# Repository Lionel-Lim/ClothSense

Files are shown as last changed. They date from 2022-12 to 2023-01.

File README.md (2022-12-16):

# ClothSense

CASA0016

DY Lim

* * *

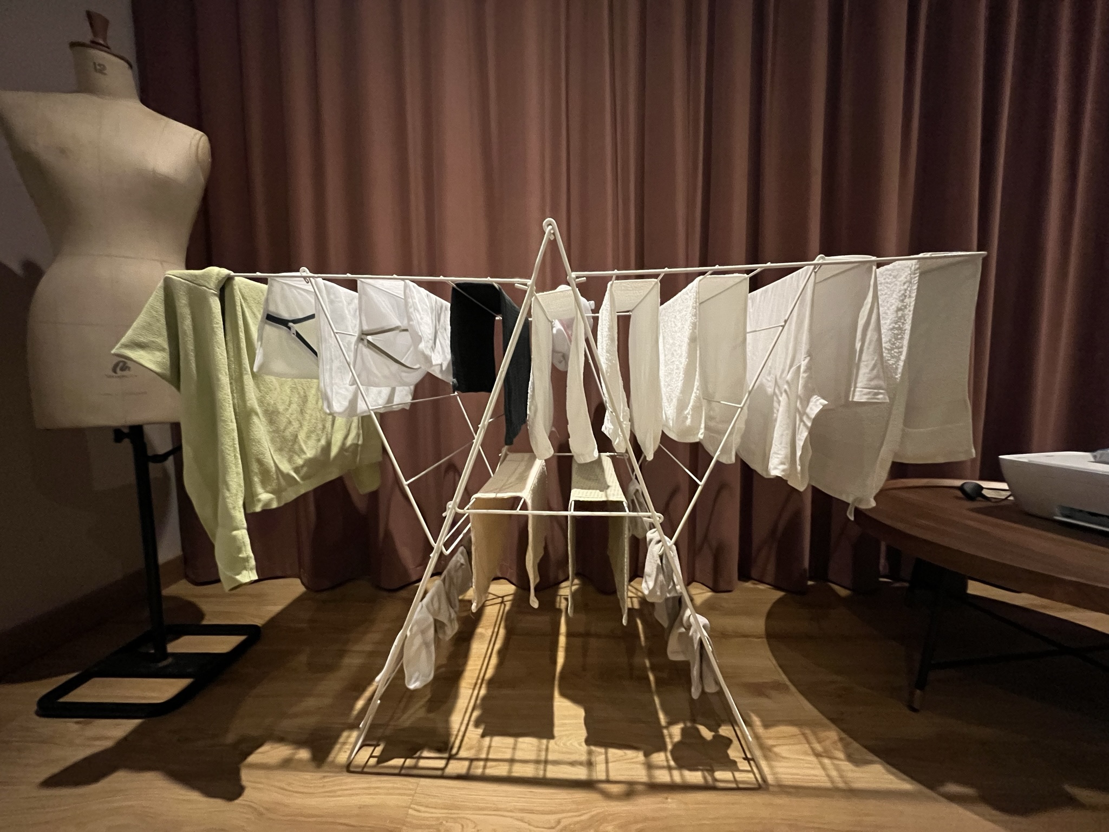
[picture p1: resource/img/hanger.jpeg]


## When is it going to be dried?

###   

### No dryer.

Energy Bill, Damage on cloth, Noise...

Every time I needed to touch the cloth to check whether it is dried or still wet.

However, it is **_hard to predict_** even if i do so. 

Also, I want to **_boost the drying process_** and want to **_know the condition_** where it is located(Bad air quality, weather).

ClothSense is going to  **monitor**:

- Temperature
- Humidity
- ~~Air Quality~~

ClothSense is going to **boost**:

- Dry State

ClothSense is going to **show:**

- Estimated Time to dry
- Current Environmental Condition

###   

## Component

- Arduino Uno (MCU)
- ~~BME680~~ DHT22 (Environment Sensor) - Digital Pin
- max7219 LED Matrix 8x32 (Display) - SPI
- NF-F12 5V PMW (Fan) - PWM
- Buttons - Digital Pin

## Workflow

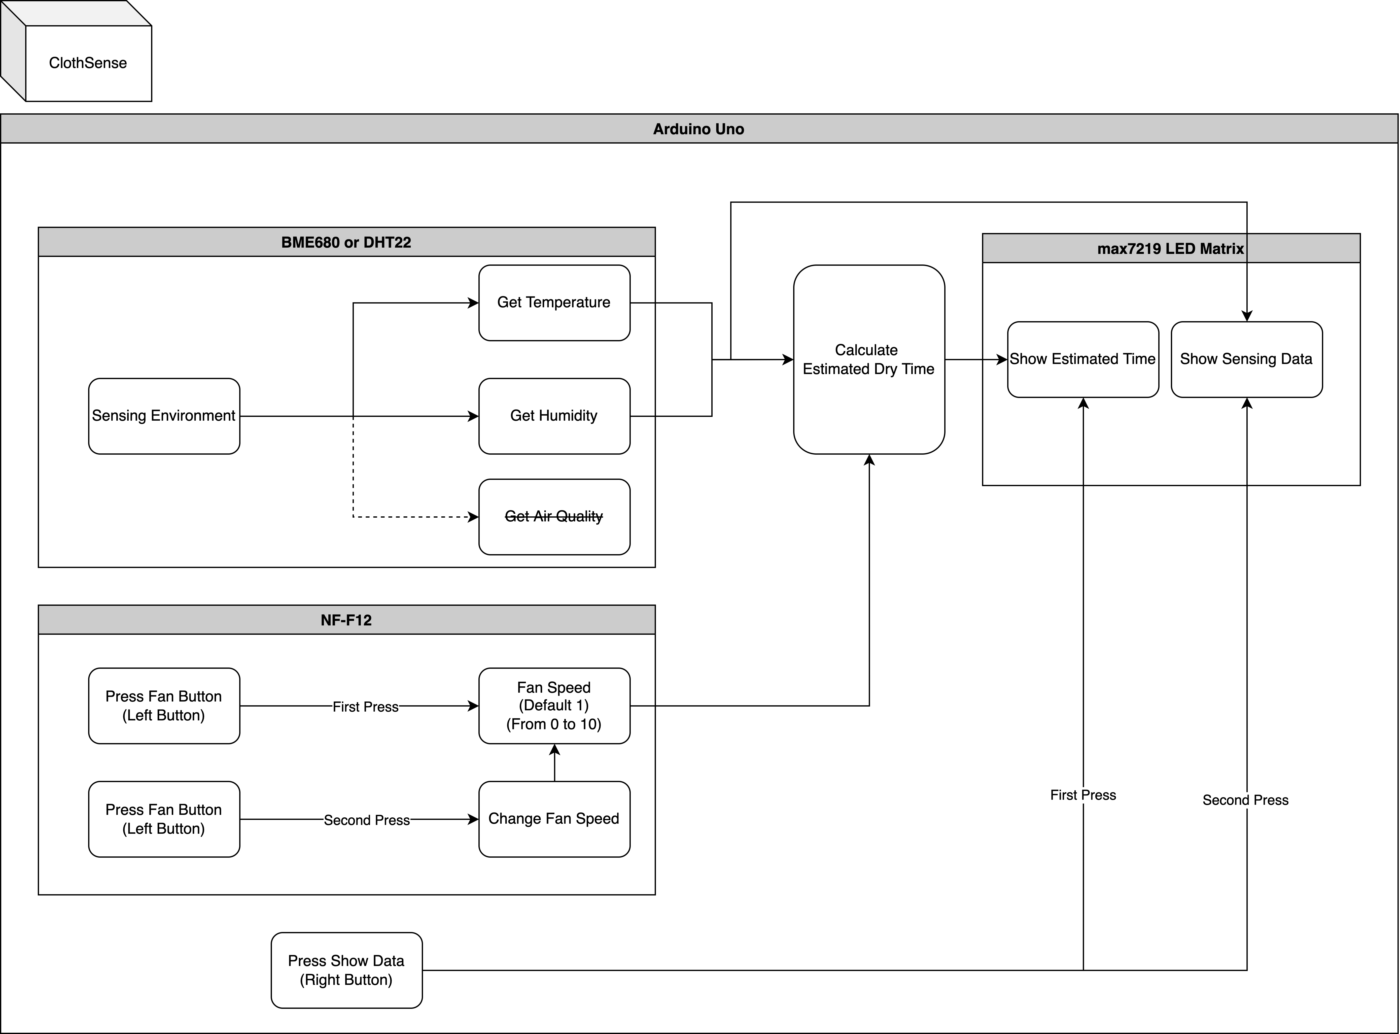
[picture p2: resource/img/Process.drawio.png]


## Build Process

### First Prototype

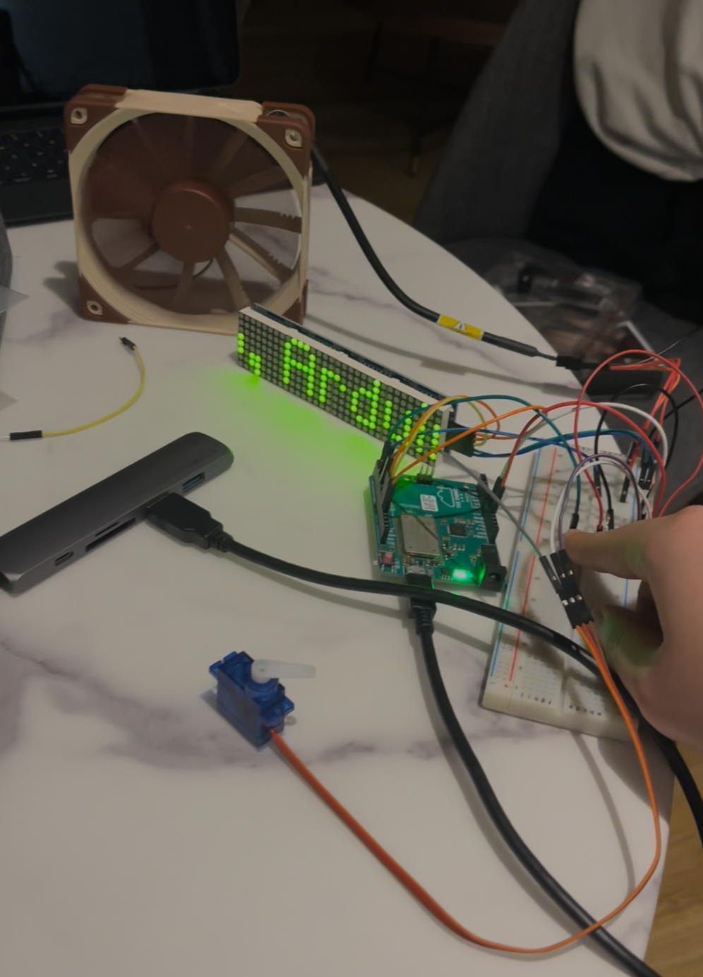
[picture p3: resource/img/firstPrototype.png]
  

Tested Fan Control using PWM control

By pressing button, Uno changes fan speed for noise control.

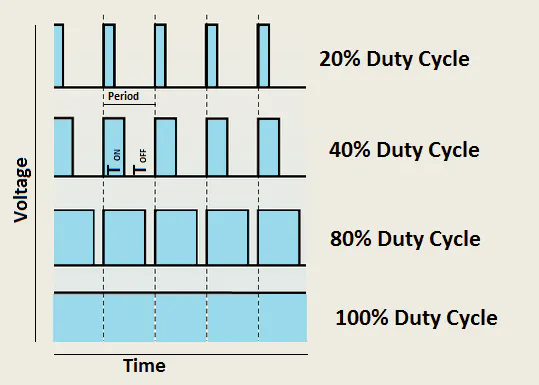
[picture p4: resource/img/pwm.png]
  

[Arduino PWM Tutorial - Arduino Project Hub](https://create.arduino.cc/projecthub/muhammad-aqib/arduino-pwm-tutorial-ae9d71)  

### Second Prototype

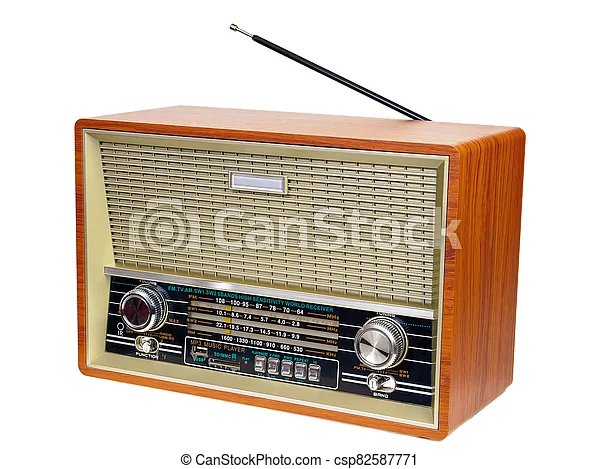
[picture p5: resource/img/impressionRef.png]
  

[Old-fashioned vintage radio isolated on a white background - | CanStock (canstockphoto.com)](https://www.canstockphoto.com/old-fashioned-vintage-radio-isolated-on-82587771.html)  

Inspired by the old fashion radios, got the idea from Prof. Andy.

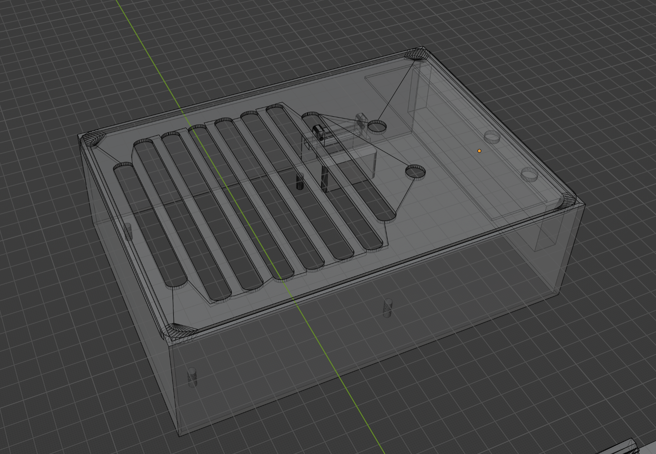
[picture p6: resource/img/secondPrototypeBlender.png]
  

3D Printing Enclosure

- Slow
- Not Precise
- Good for 3d solid object prototyping

Removed servo

Moved LED Matrix

Changed sie

### Third Prototype

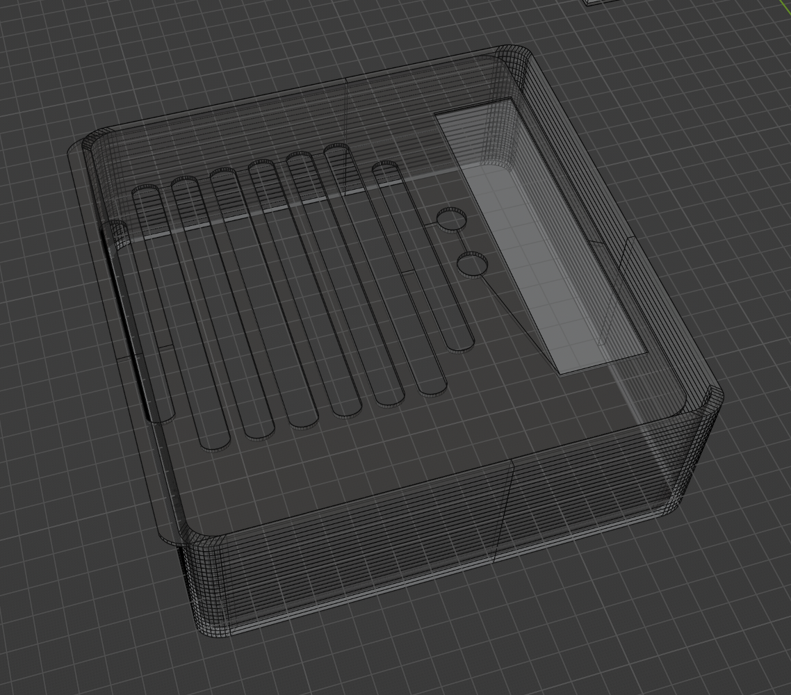
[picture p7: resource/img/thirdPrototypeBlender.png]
  

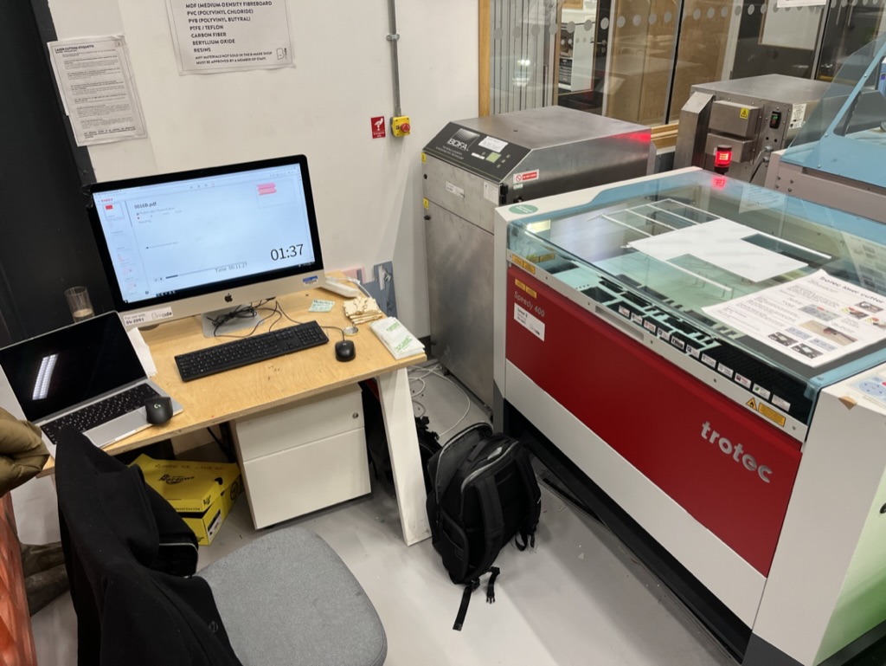
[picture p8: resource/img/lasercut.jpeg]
  

Laser cut wood enclosure

- Fast
- Precise

3D Printed top lid to hide LED matrix and for aesthetic reason

with the enclosure, the device was tested and some problems are found:

1. BME680 library uses more than 30% of maximum sketch storage. (From 70% to 117%)

- [Reduce the size and memory usage of your sketch – Arduino Help Center](https://support.arduino.cc/hc/en-us/articles/360013825179-Reduce-the-size-and-memory-usage-of-your-sketch)  
    
- Remove BME680 and use  DHT22
- Use Arduino Uno instead of Leonardo (LoRa Library)
- Optimised variables and functions

3. Did not design the component mounting

- Made some mounting brackets
- ![](./resource/img/lasercutBracket.jpeg  

### Final Build

Modularised parts

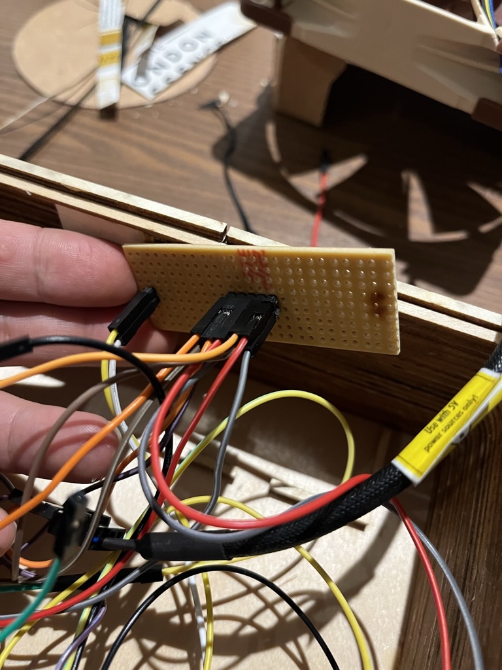
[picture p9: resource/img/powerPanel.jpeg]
 

Used DHT22

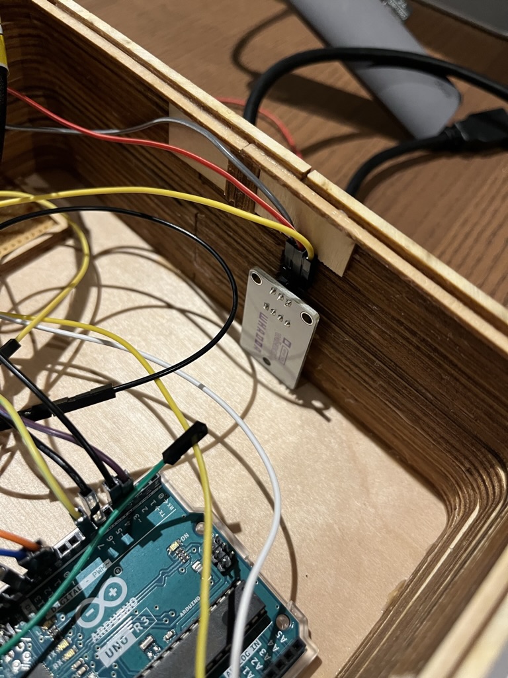
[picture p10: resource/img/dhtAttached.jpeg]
  

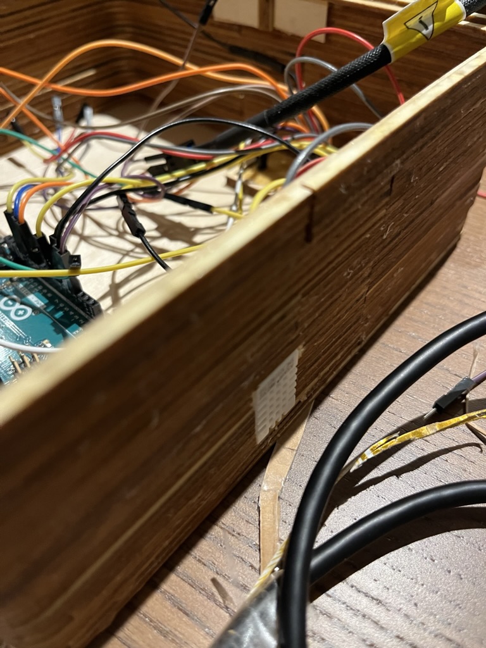
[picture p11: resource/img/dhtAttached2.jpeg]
  

Added mesh to prevent the interference between the fan and wires

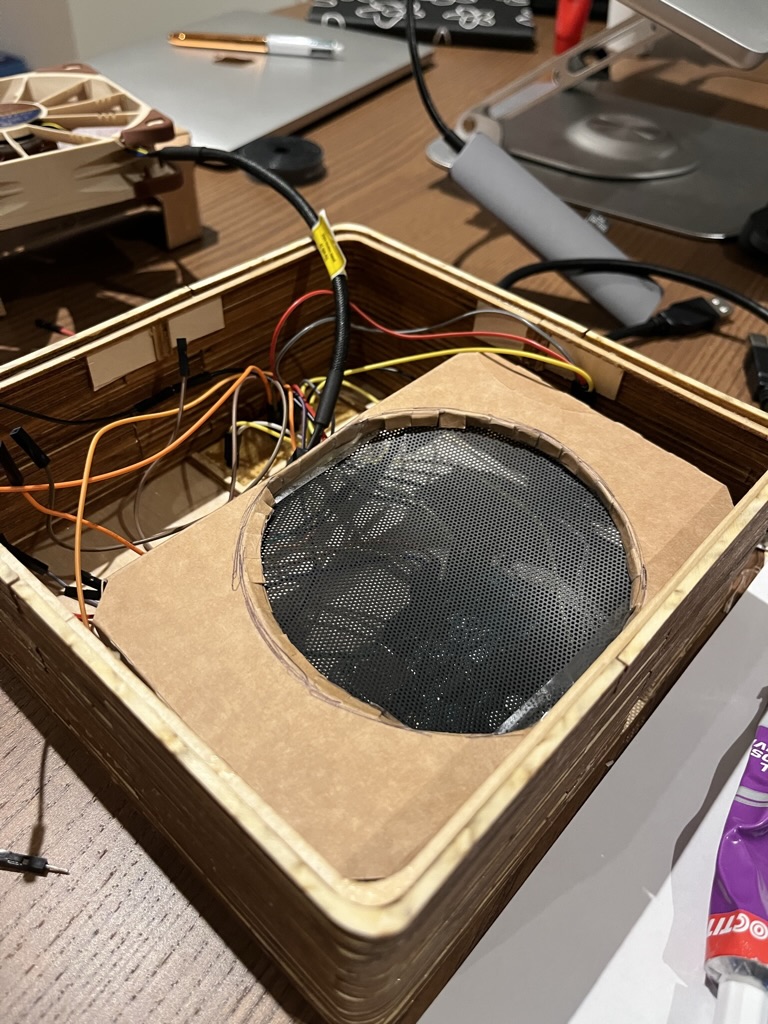
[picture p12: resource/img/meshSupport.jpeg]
  

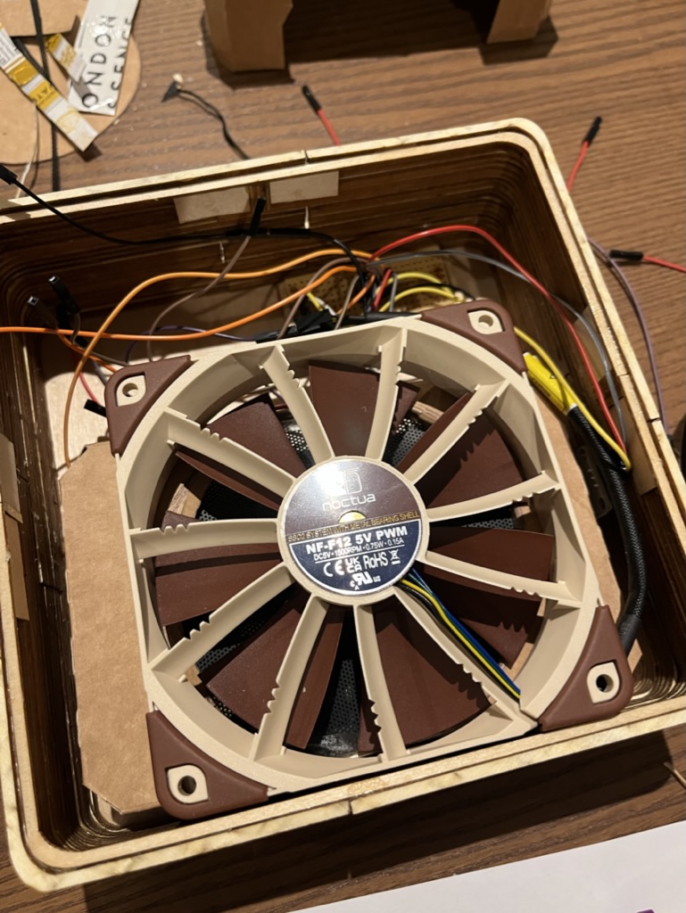
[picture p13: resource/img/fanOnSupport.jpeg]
  

Introduced the mounting bracket

  

Result

[demo](https://drive.google.com/file/d/1XH3c2ZzTV_dLAC6Vp6ikhxQ3ZIhcOEiU/view?usp=share_link)

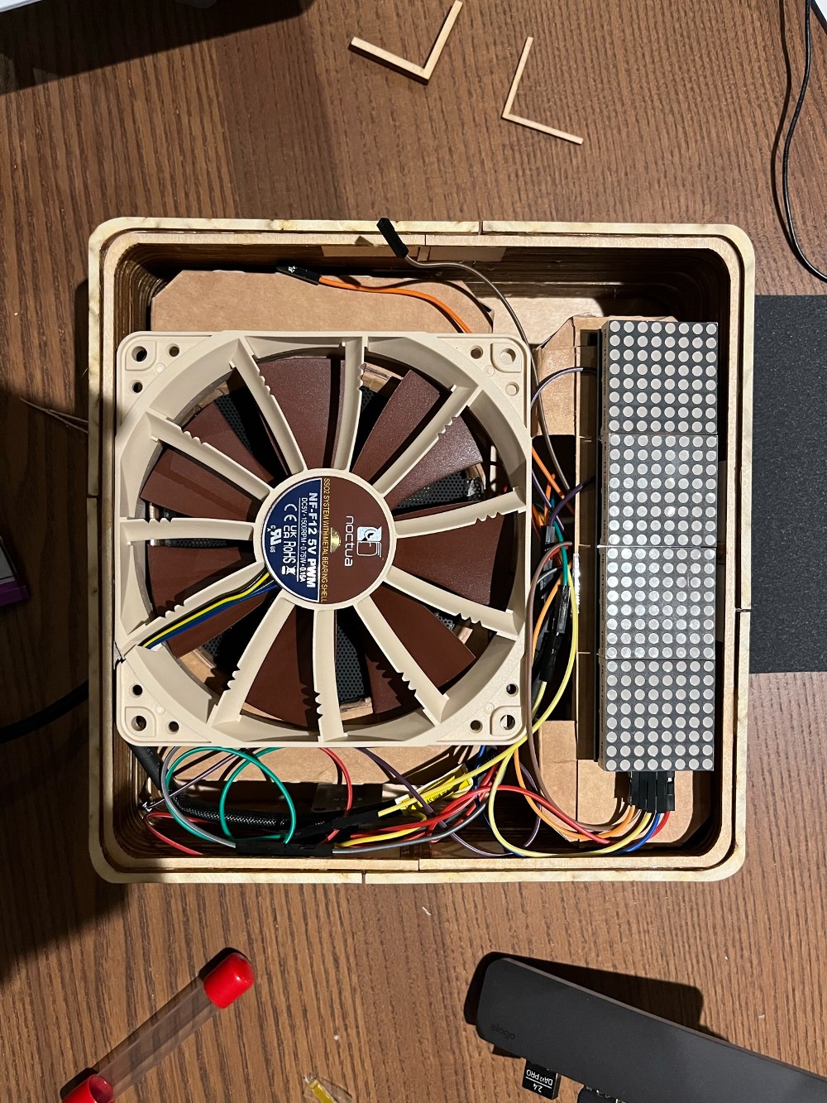
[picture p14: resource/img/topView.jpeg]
  

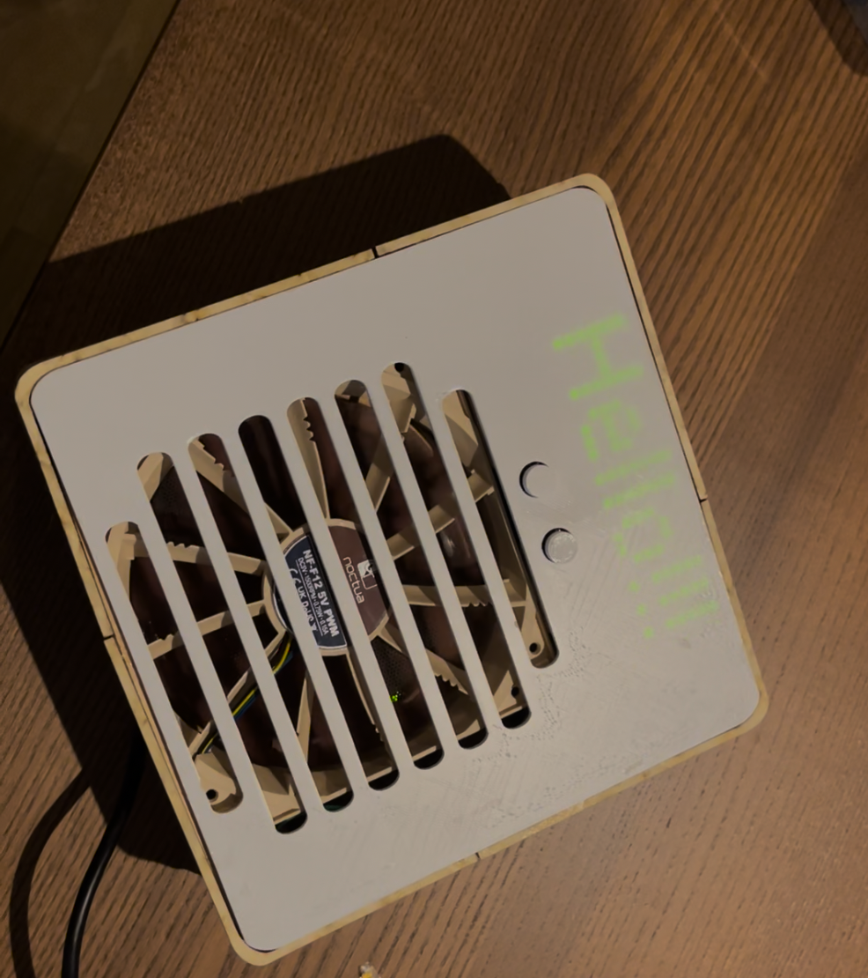
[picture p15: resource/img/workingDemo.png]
  

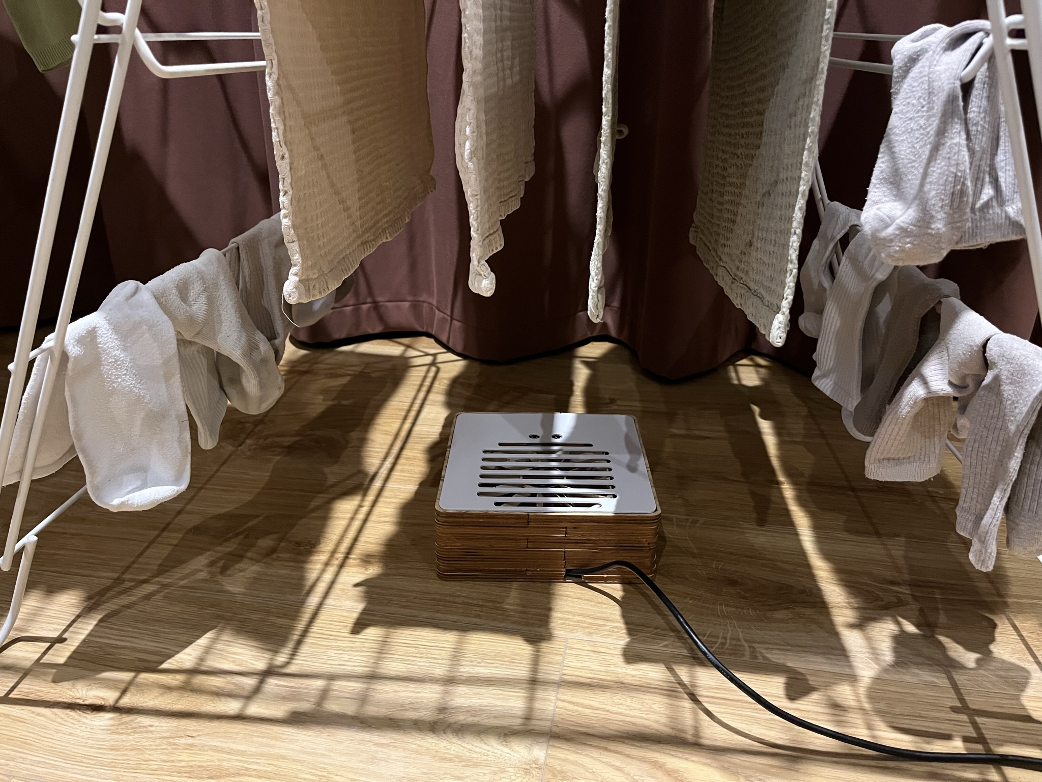
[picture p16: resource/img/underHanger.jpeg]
  

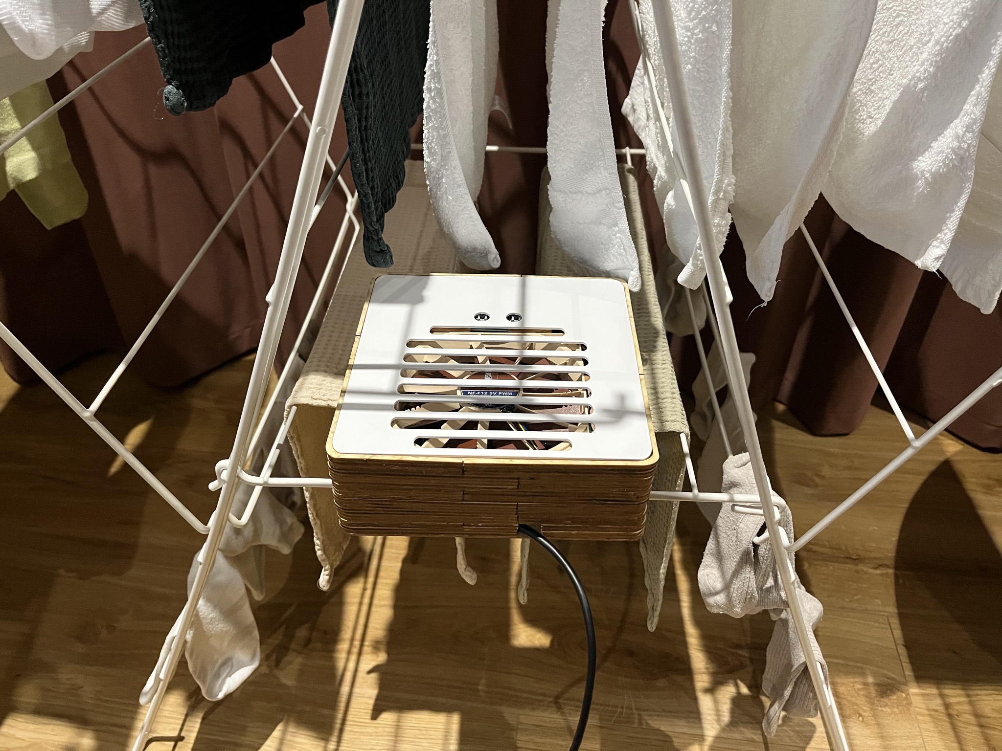
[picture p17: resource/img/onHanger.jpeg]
  

## If i had more time, I would

- Use wireless data transmission such as WiFi, LoRa...
- Improve the enclosure
- Order a custom PCB board to reduce the device size

## Where can it be used?

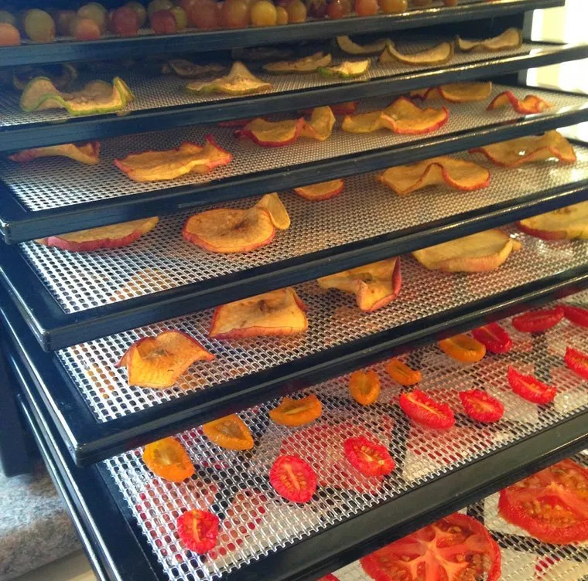
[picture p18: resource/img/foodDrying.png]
  

[A Grade Dehydrated Vegetables, Pan India, Packaging Size: 5 Kg at Rs 350/kg in New Delhi (indiamart.com)](https://www.indiamart.com/proddetail/dehydrated-vegetables-24169149248.html)  

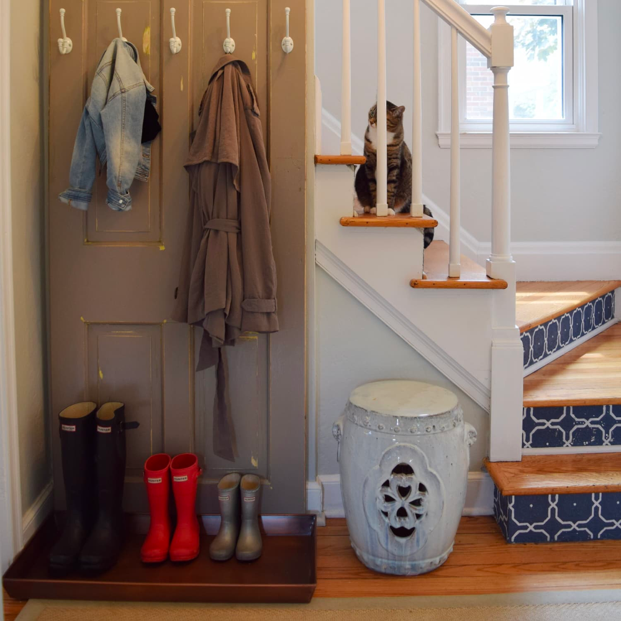
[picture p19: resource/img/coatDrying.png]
  

[9 Hat and Coat Storage Ideas When You Don't Have a Coat Closet | Apartment Therapy](https://www.apartmenttherapy.com/9-creative-ways-to-organize-your-coats-and-hats-by-the-door-when-you-dont-have-a-coat-closet-239859)  

## Lesson Learnt

- Test, Test, Test and Test.

- Even though the several design, Some improvement can be made.

- Laser Cutter is better than what I expected.

- If the prototype shape is not complicate, Laser cutter is a good option. 

- The bouncing issue is too difficult (If you only use software debouncing).

- Depends on the type of button, wire, etc..., the button needed to be calibrated.

## Reference

_Adafruit BME680_ (no date) _Adafruit Learning System_. Available at: [https://learn.adafruit.com/adafruit-bme680-humidity-temperature-barometic-pressure-voc-gas/overview](https://learn.adafruit.com/adafruit-bme680-humidity-temperature-barometic-pressure-voc-gas/overview) (Accessed: 21 November 2022).

_BME680 Breakout - Air Quality, Temperature, Pressure, Humidity Sensor - Pimoroni_ (no date). Available at: [https://shop.pimoroni.com/products/bme680-breakout](https://shop.pimoroni.com/products/bme680-breakout) (Accessed: 21 November 2022).

_Leonardo | Arduino Documentation_ (no date). Available at: [https://docs.arduino.cc/hardware/leonardo](https://docs.arduino.cc/hardware/leonardo) (Accessed: 28 November 2022).

_OctoPrint Login_ (no date). Available at: [http://octopi-prusa-2.celab/login/?redirect=%2F%3F&permissions=STATUS%2CSETTINGS\_READ](http://octopi-prusa-2.celab/login/?redirect=%2F%3F&permissions=STATUS%2CSETTINGS_READ) (Accessed: 6 December 2022).

_PWM conflict? One DC servo, one PWM fan motor - Using Arduino / Motors, Mechanics, Power and CNC_ (2020) _Arduino Forum_. Available at: [https://forum.arduino.cc/t/pwm-conflict-one-dc-servo-one-pwm-fan-motor/662796](https://forum.arduino.cc/t/pwm-conflict-one-dc-servo-one-pwm-fan-motor/662796) (Accessed: 3 December 2022).

_UNO R3 | Arduino Documentation_ (no date). Available at: [https://docs.arduino.cc/hardware/uno-rev3](https://docs.arduino.cc/hardware/uno-rev3) (Accessed: 14 December 2022).

## Link
Github - https://github.com/Lionel-Lim/ClothSense

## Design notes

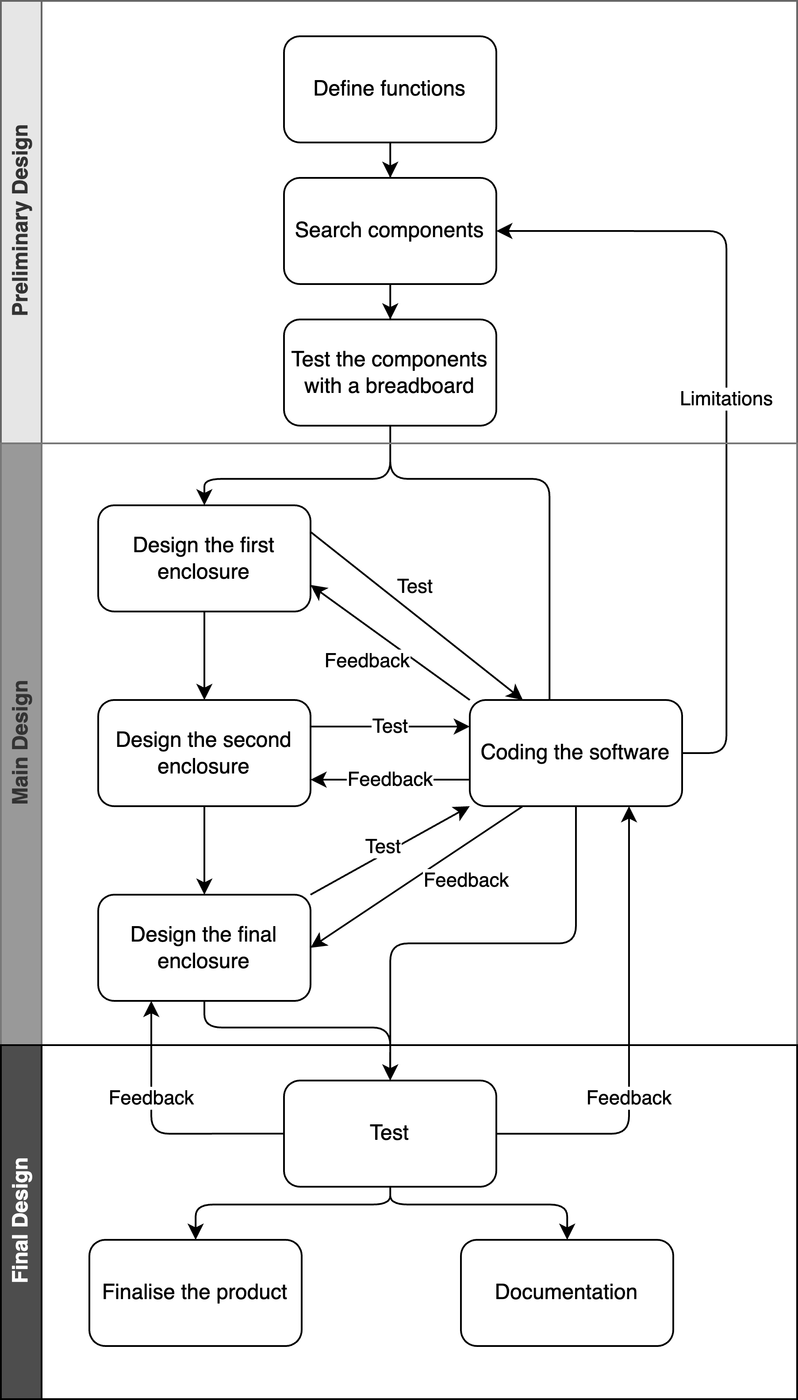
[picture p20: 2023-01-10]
resource/img/designProcess.png

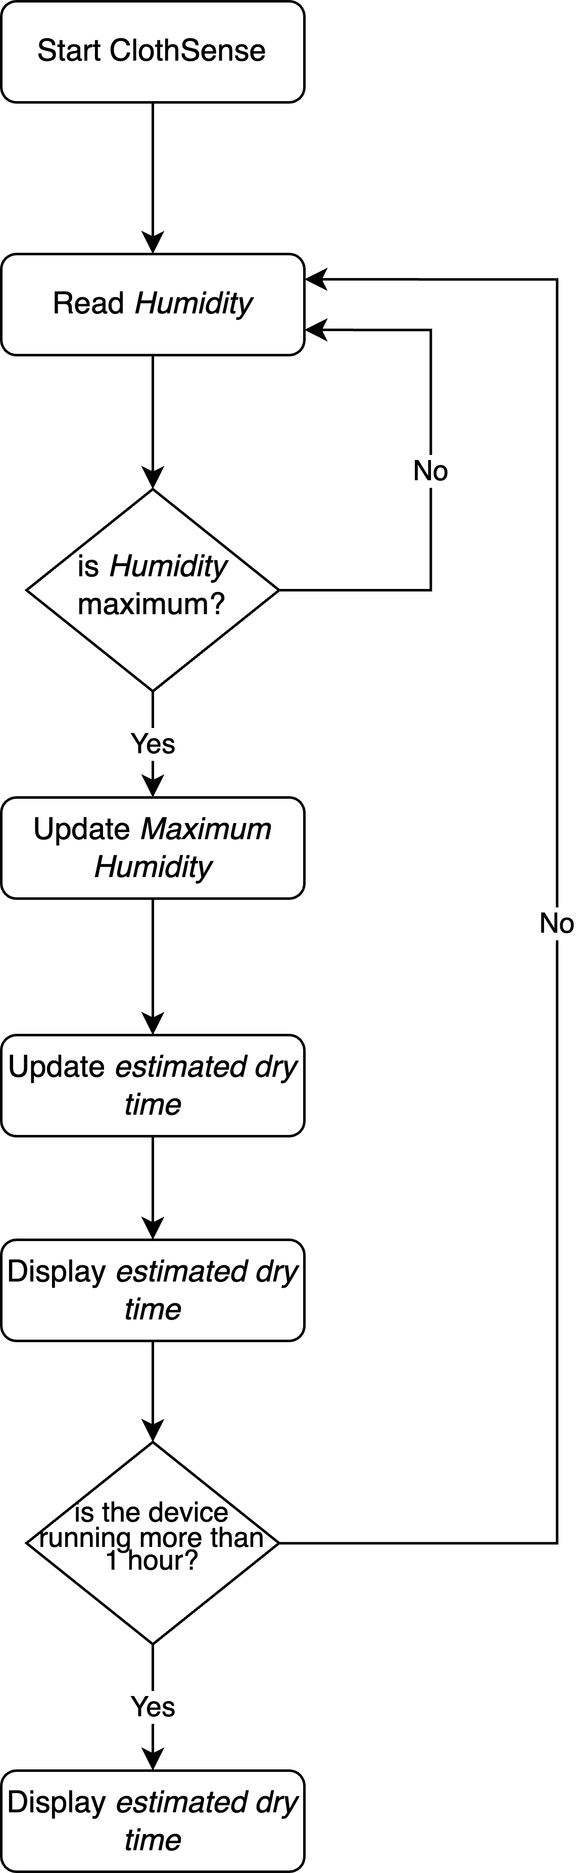
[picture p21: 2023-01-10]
resource/img/calculateDryTime.png

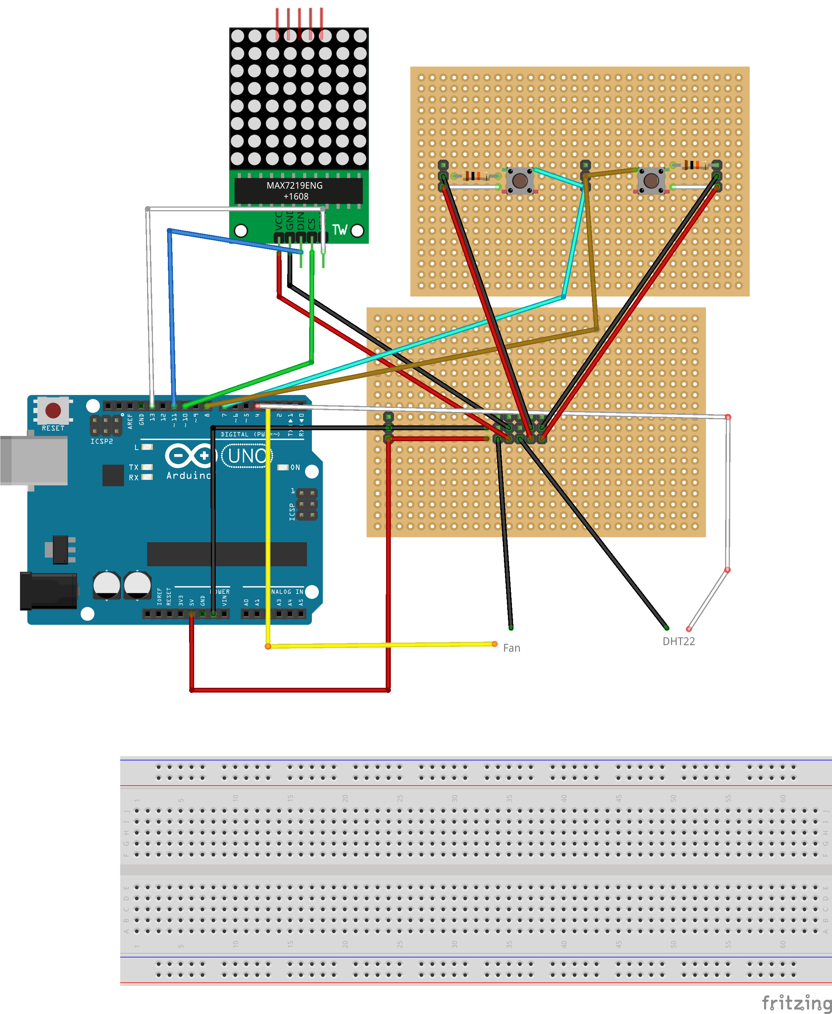
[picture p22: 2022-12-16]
resource/img/wireSketch.png

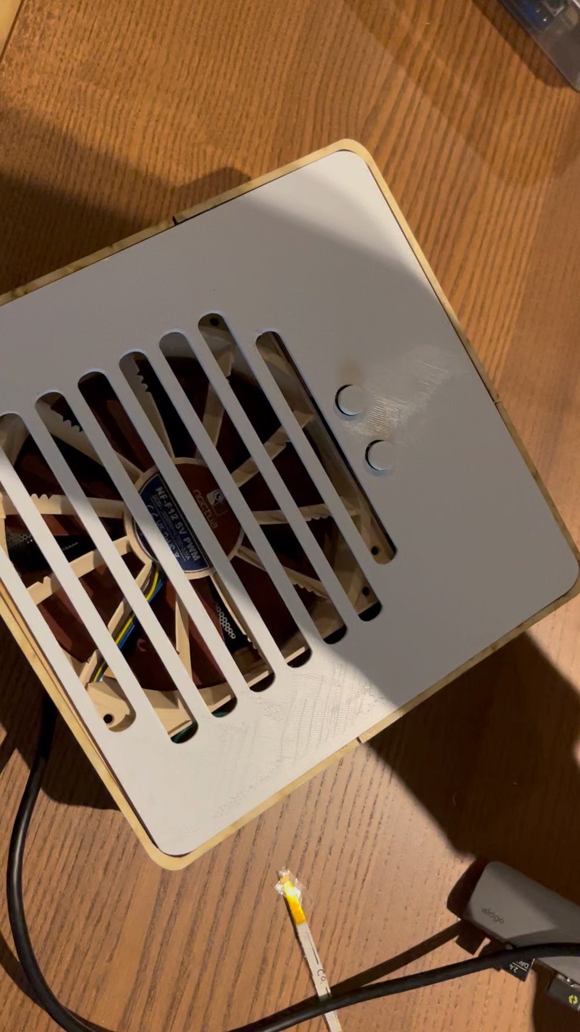
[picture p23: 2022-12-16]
resource/img/top2.jpeg

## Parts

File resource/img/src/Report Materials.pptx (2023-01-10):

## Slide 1

E

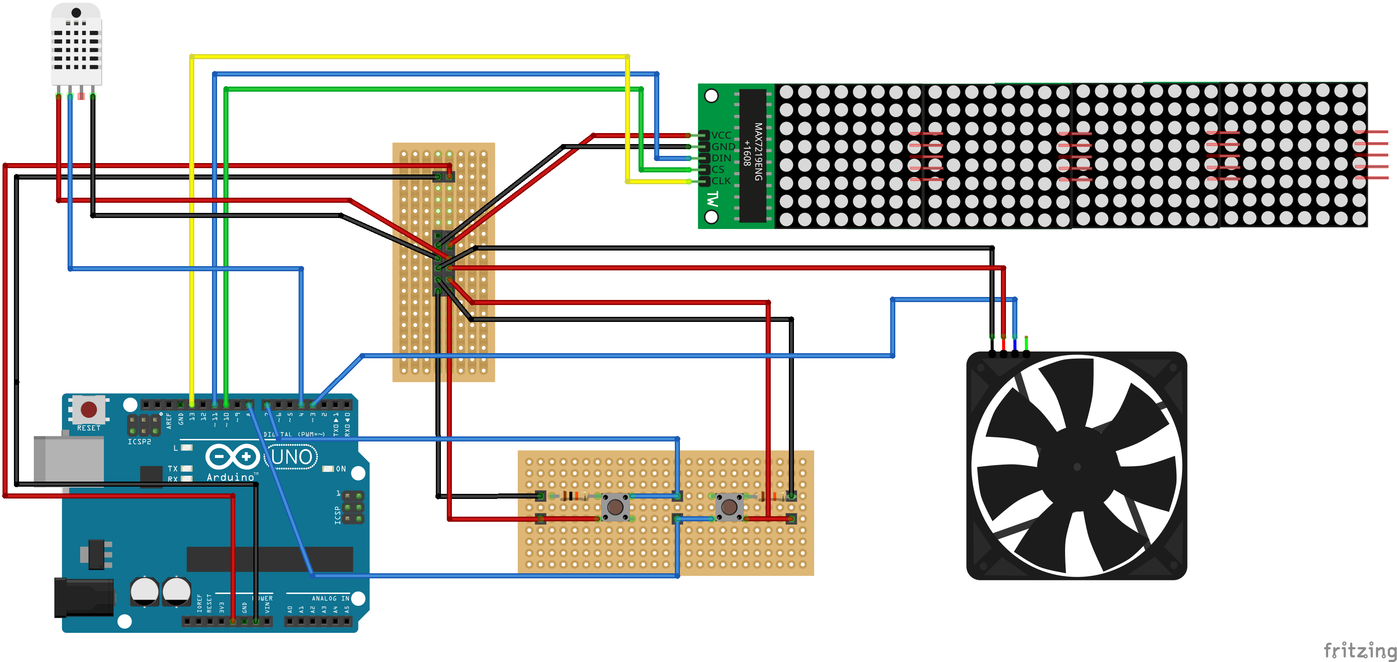
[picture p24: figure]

D

B

C

F

A

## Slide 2

0%

HIGH

LOW

HIGH

50%

LOW

HIGH

100%

LOW

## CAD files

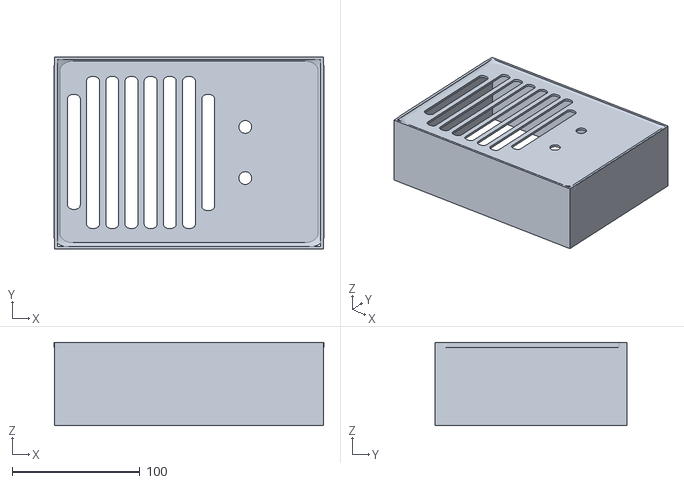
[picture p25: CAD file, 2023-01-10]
resource/models/Printing/all_V1.stl
211.1 x 150.1 x 65.0

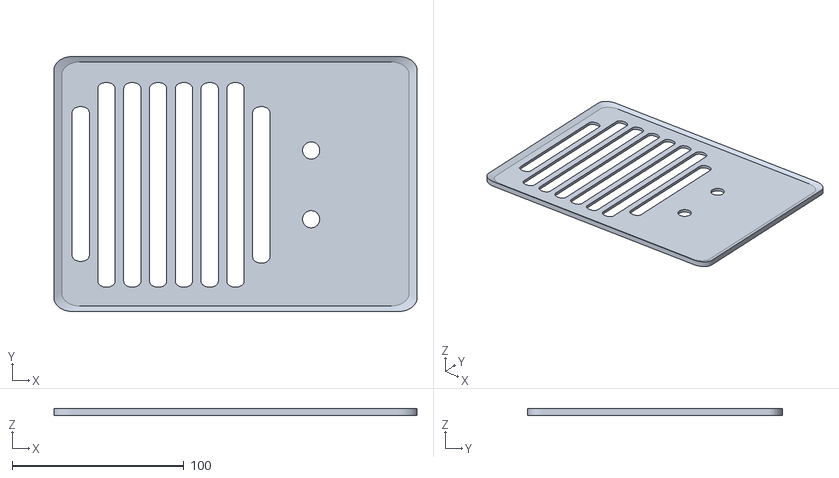
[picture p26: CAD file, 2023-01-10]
resource/models/Printing/lid_V1.stl
211.1 x 148.4 x 4.00

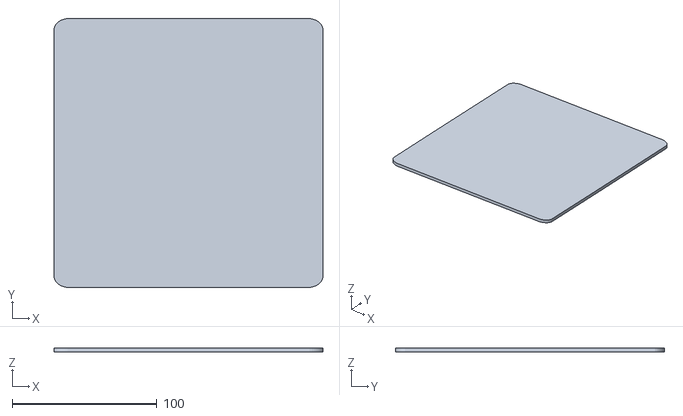
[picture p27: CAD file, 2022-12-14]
resource/models/Printing/Base_V2.stl
186.0 x 186.0 x 3.00

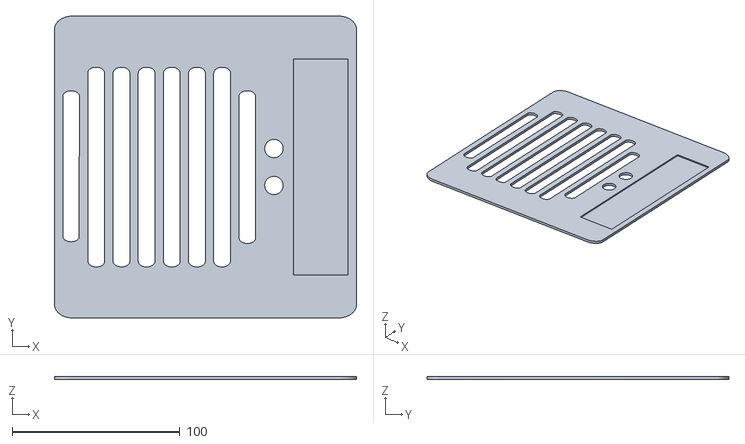
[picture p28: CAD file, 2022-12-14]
resource/models/Printing/mockup_V2.stl
180.0 x 179.8 x 2.00

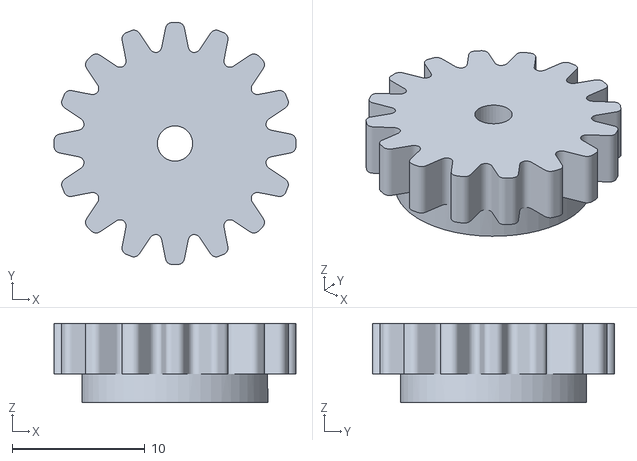
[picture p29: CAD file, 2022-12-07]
resource/models/Printing/Pinion_Gear_Mini_Version.STL
18.2 x 18.2 x 5.97

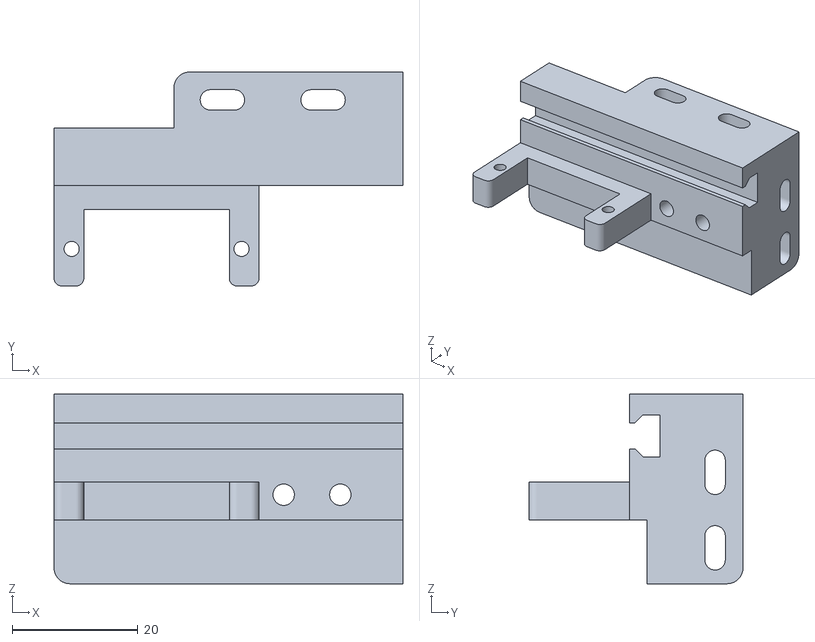
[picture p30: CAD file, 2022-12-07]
resource/models/Printing/Motor_Bracket_Mini_Version.STL
55.5 x 34.0 x 30.1

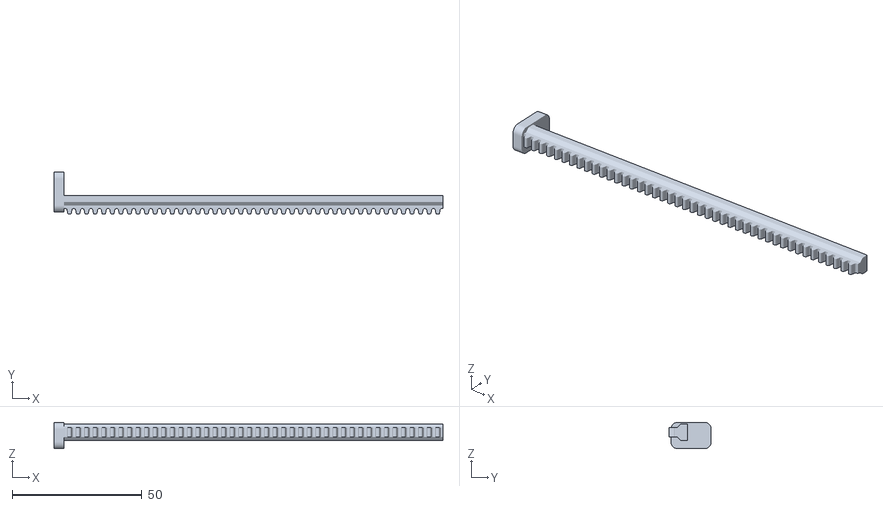
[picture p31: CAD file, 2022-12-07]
resource/models/Printing/Pusher_150mm_Long.STL
150.0 x 16.3 x 10.2

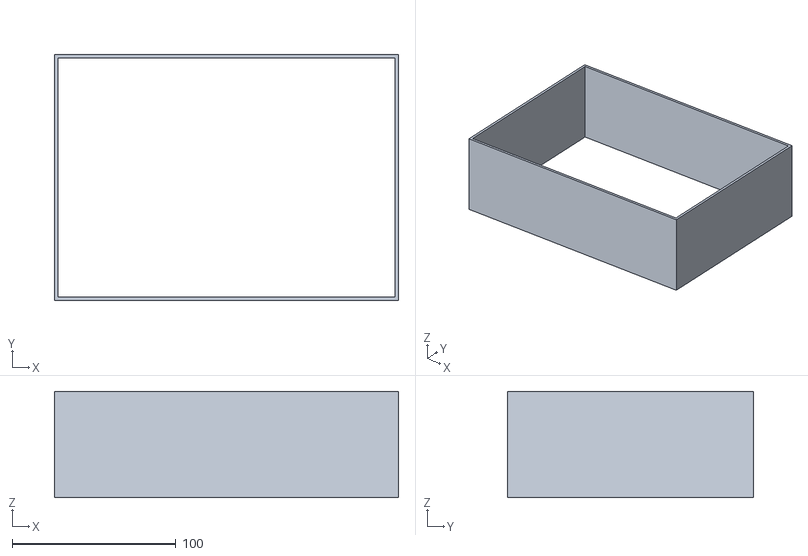
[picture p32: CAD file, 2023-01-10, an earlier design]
resource/models/Printing/Base_V1.stl
210.0 x 150.0 x 65.0

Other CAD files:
resource/models/mockup.blend

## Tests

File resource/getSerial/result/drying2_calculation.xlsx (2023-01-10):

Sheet: drying_2
Test at 17:52 |  |  |  |  | MAX | 55 | 8
21 | 50 | 5003 | 00:00:05.3 | 54.00083641 | MIN | 47 |  | 20 | 49 | 5003
21 | 51 | 10004 | 00:00:10.4 | 54.00125379 |  |  |  | 20 | 49 | 10004
21 | 51 | 15003 | 00:00:15.3 | 54.00167063 |  |  |  | 20 | 49 | 5003
21 | 51 | 20004 | 00:00:20.4 | 54.00208691 |  |  |  | 20 | 49 | 10003
21 | 51 | 25004 | 00:00:25.4 | 54.00250266 |  |  |  | 20 | 49 | 15003
21 | 51 | 30003 | 00:00:30.3 | 54.00291785 |  |  |  | 20 | 49 | 20003
21 | 52 | 35003 | 00:00:35.3 | 54.0033325 |  |  |  | 20 | 49 | 25004
21 | 52 | 40003 | 00:00:40.3 | 54.00374661 |  |  |  | 20 | 49 | 30003
21 | 52 | 45003 | 00:00:45.3 | 54.00416016 |  |  |  | 20 | 49 | 35003
21 | 52 | 50003 | 00:00:50.3 | 54.00457317 |  |  |  | 20 | 49 | 40004
21 | 52 | 55003 | 00:00:55.3 | 54.00498564 |  |  |  | 20 | 49 | 45003
21 | 52 | 60003 | 00:01:00.3 | 54.00539756 |  |  |  | 20 | 49 | 50003
21 | 52 | 65003 | 00:01:05.3 | 54.00580893 |  |  |  | 20 | 50 | 55003
21 | 53 | 70003 | 00:01:10.3 | 54.00621975 |  |  |  | 20 | 50 | 60003
21 | 52 | 75003 | 00:01:15.3 | 54.00663003 |  |  |  | 20 | 50 | 65003
21 | 52 | 80003 | 00:01:20.3 | 54.00703976 |  |  |  | 20 | 49 | 70003
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

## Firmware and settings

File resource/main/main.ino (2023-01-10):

// Import library
#include <MD_Parola.h>
#include <MD_MAX72xx.h>
#include <SPI.h>
#include <DHT.h>
#include <DHT_U.h>

// Pinout Setting
#define CS_PIN    10
#define DATA_PIN  11
#define CLK_PIN   13
#define buttonPin 6 
#define infoButtonPin 8
#define pwmPin 3
#define DHTPin 4 

// Hardware Setting
#define HARDWARE_TYPE MD_MAX72XX::FC16_HW
#define MAX_DEVICES 4
#define DHTTYPE DHT22   // DHT 22

MD_Parola P = MD_Parola(HARDWARE_TYPE, CS_PIN, MAX_DEVICES);
DHT dht(DHTPin, DHTTYPE);   // Initialize DHT sensor.

// LED Config
uint8_t scrollSpeed = 25;    // default frame delay value
textEffect_t scrollEffect = PA_PRINT;
textEffect_t scrollRemoveEffect = PA_SCROLL_LEFT;
textPosition_t scrollAlign = PA_LEFT;
uint16_t scrollPause = 2000; // in milliseconds
  // Global message buffers shared by Serial and Scrolling functions
#define	BUF_SIZE	70
char curMessage[BUF_SIZE] = { "" };
char newMessage[BUF_SIZE] = { "Hello!!!" };
#define	Default_SIZE	50
char defaultCurMessage[Default_SIZE] = { "" };
char defaultNewMessage[Default_SIZE] = { "^  -" };
bool newMessageAvailable = true;

// variables Setting:
const int ledInterval = 100;
const int buttonInterval = 50;
const int DHTInterval = 5000;
const int goToDefaultDisplayInterval = 10000;
const int countDownInterval = 5000;

char estimatedHHmmTime[BUF_SIZE] = { "" };
int goToDefaultStatus = 0;
int buttonState = 1;  // variable for reading the pushbutton status
int infoButtonState = 1;
int buttonLevel;
int lastButtonState = 1;
int lastInfoButtonState = 1;
int fanSpeed = 0;
int defaultDisplayCount = 0;
int temp;
int countEstimatedTime = 0;
float humd;
float maxHumd = 0;
float startHumd = 0;
unsigned long currentMillis = 0;
unsigned long previousButtonMillis = 0;
unsigned long previousInfoButtonMillis = 0;
unsigned long previousDHTMillis = 0;
unsigned long previousDefaultDisplayMillis = 0;
unsigned long previousCountDownMillis = 0;
unsigned long estimatedDryTime = 0;
unsigned long remainedTime = 0;
bool fanButtonWasPressed = false;
bool infoButtonWasPressed = false;

// Functions
void onPressed() {
  unsigned long currentTime = millis();
  boolean buttonIsPressed = digitalRead(buttonPin) == LOW;

  // Check for button state change and do debounce
  if (buttonIsPressed != fanButtonWasPressed &&
      currentTime  -  previousButtonMillis > buttonInterval){
    // Button state has changed
    fanButtonWasPressed = buttonIsPressed;
    previousButtonMillis = currentTime;
    if (fanButtonWasPressed){
    }
    else
    {
     if(buttonLevel == 10){
        buttonLevel = 0;
      }else{
        buttonLevel = buttonLevel + 1;
      }
      Serial.print("Level is ");
      Serial.println(buttonLevel);
      sprintf(newMessage, "Fan %d", buttonLevel);
      strcpy(curMessage, newMessage);
      newMessageAvailable = true;
      previousDefaultDisplayMillis = currentMillis;
      goToDefaultStatus = 0;
      P.displayText(curMessage, scrollAlign, scrollSpeed, scrollPause, scrollEffect, scrollRemoveEffect);
    }
  }
}

void onInfoBtnPressed() {
  unsigned long currentTime = millis();
  boolean buttonIsPressed = digitalRead(infoButtonPin) == LOW;

  // Check for button state change and do debounce
  if (buttonIsPressed != infoButtonWasPressed &&
      currentTime  -  previousInfoButtonMillis > buttonInterval){
    // Button state has changed
    infoButtonWasPressed = buttonIsPressed;
    previousButtonMillis = currentTime;
    if (infoButtonWasPressed){
    }
    else
    {
      sprintf(newMessage, "Temperature : %d, Humidity : %s", temp, String(humd,2).c_str());
      strcpy(curMessage, newMessage);
      newMessageAvailable = true;
      previousDefaultDisplayMillis = currentMillis;
      goToDefaultStatus = 0;
      P.displayText(curMessage, scrollAlign, scrollSpeed, scrollPause, scrollRemoveEffect, scrollRemoveEffect);
    }
  }
}

void goToDefaultDisplay(){
  countEstimatedTime += 1;
  if(countEstimatedTime == 20000){
    previousDefaultDisplayMillis += goToDefaultDisplayInterval;
    P.displayClear();
    P.displayReset();
    P.displayText(estimatedHHmmTime, PA_CENTER, scrollSpeed, 2500, PA_SCROLL_LEFT, PA_SCROLL_LEFT);
    countEstimatedTime = 0;
    goToDefaultStatus += 1;
    if (goToDefaultStatus == 3){
      goToDefaultStatus = 0;
    }
  }
  else if(currentMillis - previousDefaultDisplayMillis >= goToDefaultDisplayInterval && goToDefaultStatus == 0){
    previousDefaultDisplayMillis += goToDefaultDisplayInterval;
    goToDefaultStatus = 1;
    defaultDisplayCount += 1;
    P.displayClear();
    P.displayReset();
    if (humd >= 80){
      sprintf(defaultNewMessage, "T    T");
    }
    else if (humd >= 50){
      sprintf(defaultNewMessage, "-    -");
    }
    else{
      sprintf(defaultNewMessage, "^     ^");
    }
    strcpy(defaultCurMessage, defaultNewMessage);
    P.displayText(defaultCurMessage, PA_CENTER, scrollSpeed, 5000, PA_SCROLL_UP, PA_SCROLL_DOWN);
  }
}

void readDHT() {
  if (currentMillis - previousDHTMillis >= DHTInterval){
    previousDHTMillis += DHTInterval;
    if (maxHumd < dht.readHumidity()){
      maxHumd = dht.readHumidity();
      estimatedDryTime = calculateEstimatedDryTime(maxHumd);
      Serial.print("Updated ");
      Serial.println(estimatedHHmmTime);
    }
    temp = dht.readTemperature();
    humd = dht.readHumidity();
    Serial.print(temp);
    Serial.print(" / ");
    Serial.print(humd);
    Serial.print(" / ");
    Serial.print(maxHumd);
    Serial.print(" / ");
    Serial.println(millis());
  }
}

void calculateDryTime() {
  if(humd > maxHumd){
    //
  }
}

unsigned long calculateEstimatedDryTime(float HUMIDITY) {
  unsigned long estimatedCount = 3600000 / DHTInterval;
  float estimatedHumd = 0;
  while(millis()<=3600000){
    if(millis() <= 10000){
      estimatedHumd = (0.00000003*pow(estimatedCount/16,3)) + 
      (-0.00007*pow(estimatedCount/16,2)) + 
      (0.0067*estimatedCount/16) + 
      (HUMIDITY + 4); // Simplified equation before storing data
    }else{
      estimatedHumd = (0.00000003*pow(estimatedCount/16,3)) + 
      (-0.00007*pow(estimatedCount/16,2)) + 
      (0.0067*estimatedCount/16) + 
      (startHumd + (abs(HUMIDITY - startHumd)/2));
    }
    if(abs(estimatedHumd - startHumd) < 0.01){
      return estimatedCount * DHTInterval;  // convert data row number to time
    }
    else if(estimatedCount >= 10000){
      return 0; // If cannot find, return 0
    }
    else{
      estimatedCount += 1;
    }
  }
}

void convertMillsToHHmm(unsigned long milli){
  unsigned long minutes;
  unsigned long hours;

  minutes = milli / 60000;
  hours = minutes / 60;
  minutes %= 60;
  hours %= 24;

  sprintf(estimatedHHmmTime, "Estimated Time : %lu hours %lu minutes", hours, minutes);
}

void countDownTime(){
  if (currentMillis - previousCountDownMillis >= countDownInterval){
    previousCountDownMillis += countDownInterval;
    remainedTime = estimatedDryTime - millis();
    convertMillsToHHmm(remainedTime);
  }
}

void setup() {
  // Set Serial port
  Serial.begin(9600);
  Serial.println("Activating ClothSense...");

  // DHT Init
  pinMode(DHTPin, INPUT);
  dht.begin();
  readDHT();
  temp = dht.readTemperature();
  humd = dht.readHumidity();
  startHumd = humd;
  estimatedDryTime = calculateEstimatedDryTime(humd);
  convertMillsToHHmm(estimatedDryTime);
  Serial.println(estimatedHHmmTime);
  Serial.print(temp);
  Serial.print(" / ");
  Serial.print(humd);
  Serial.print(" / ");
  Serial.println(millis());

  // Buttons Init
  pinMode (buttonPin, INPUT);
  pinMode(infoButtonPin, INPUT);

  // initialize the PWM pin as an output:
  pinMode(pwmPin, OUTPUT);

  // Display Init
  P.begin();
  P.displayText(curMessage, scrollAlign, scrollSpeed, scrollPause, scrollRemoveEffect, scrollRemoveEffect);
  strcpy(curMessage, newMessage);
}

void loop() {
  currentMillis = millis();

  onPressed();
  onInfoBtnPressed();

  goToDefaultDisplay();
  readDHT();
  countDownTime();

  fanSpeed = buttonLevel * 25.5; //buttonLevel range is 0 to 10
  analogWrite(pwmPin, fanSpeed);
  if (P.displayAnimate()){
    P.displayReset();
  }
}

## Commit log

2022-11-28 Added General Concept
    [wire.fzz]
2022-12-05 changed project subject
    [mockup.blend]
2022-12-07 preparing 3d printing
    [Motor_Bracket_Mini_Version.STL, Pinion_Gear_Mini_Version.STL, Pusher_150mm_Long.STL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]
2022-12-14 Final Crit
    [Base_V2.stl, mockup.blend, mockup_V2.stl]
2022-12-16 update imgs
    [Base_V2.stl, Motor_Bracket_Mini_Version.STL, Pinion_Gear_Mini_Version.STL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]
2023-01-10 regular update
    [Base_V1.stl, all_V1.stl, drying.csv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]
